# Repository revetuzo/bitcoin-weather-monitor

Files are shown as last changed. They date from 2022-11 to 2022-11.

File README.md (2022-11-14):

# bitcoin-weather-monitor

The Bitcoin weather monitor shows Bitcoin and weather data on a small TFT display and is powered by an ESP8266 NodeMCU board.

presentation

Bitcoin-weather-monitor

Shopping list:
- NodeMCU v3.4 ESP8266 board (31.2 mm x 58 mm)
- 1.77" TFT SPI display (128 x 160) with ST7735 driver (other sizes with the same resolution and driver may work too)
- GY-21 breakout board for the HTU21 or SHT21 temprature and humidity sensor
- cables with female/female Dupont connectors, approx. 10cm length
- some M2.5x8 and short M3 screws
- a 10 Ohm resistor and some heat-shrink tube (optional) (+ a soldering iron)

Instructions:
- print the enclosure on your 3D printer (four parts: enclosure, foot, backplate, sensor rack)
- solder the header pins to the PCBs if they do not come preassembled
- assemble the electronics as shown in the Fritzing drawing (10 Ohm resistor is optional, a simple wire is fine as well)
  - the drawing shows a BMP180 sensor, but the SHT21/HTU21 has the same pinout
- mount the electronics in the enclosure with the M2.5 and M3 screws (you need a long screwdriver and maybe a pair of tweezers)
- assemble the enclosure and the sensor rack
- get an Openweathermap free API key
- find your geographical location on OpenStreetMap
- run your own Bitcoin node (optional, but highly recommended anyway!)
- install Arduino IDE 1.8.x
- install ESP8266 core in Arduino IDE
- install libraries in Arduino IDE:
  - ArduinoHttpClient
  - ArduinoJson
  - Adafruit_GFX
  - Adafruit_ST7735
  - Sodaq_SHT2x
- find and follow instructions on how to connect your NodeMCU board with Arduino IDE via USB
- modify the .ino sketch file:
  - #define MY_TZ, this string defines your timezone and DST rules (set to GMT/London by default)
  - point char mempoolserver[] at your own node or just leave it at the default mempool.space address
  - char weatherAPIString: here you have to place your latitude, longitude, and Openweathermap API key
  - enter your WiFi SSID and password in arduino_secrets.h
  - (optional) you can change the date format in the tftClockScreen() function (default is European / German style)
  - (optional) you can change the temperature units in the tftTempWeatherScreen() function
  - (optional) change the data update intverval (5 min) and time per screen (5 s) with int dataUpdateInterval and int timePerScreen in the sketch header
- compile the sketch and upload to your NodeMCU board
- use the Serial Monitor during first startup to check that all data are correctly retrieved
  
Notes:
- The holes for the screws can be loose or tight, depending on how well your printer profile is tuned. To tune the hole sizes, you may play with the flow settings, or use the horizontal hole expansion in Cura 5.x. The hole diameters work fine on my Ender 3 V2 with direct drive mod and a 0.3mm nozzle.
- NTP is included in the latest ESP8266 core library and does not require additional libraries. Sync is automatically performed whenever we turn on WiFi.
- See https://github.com/nayarsystems/posix_tz_db/blob/master/zones.csv for timezone strings.
- We put the ESP8266 into sleep mode as much as possible. WiFi is only turned on during data update. Otherwise, the module is put into "light sleep" mode. This requires some code tweaking, but reduces the current draw by approximately 8 mA and reduces the heat load on the temperature sensor. See the function lightSleep() for the annoying details.
- The 10 Ohm resistor for the TFT LED is optional. It reduces the screen brightness a bit and reduces the current draw by approximately 15 mA (roughly 30%).
- The sensor has to be placed outside the enclosure, because the device has a constant power consumption of 160 mW, which heats the sensor too much for reliable measurements.
- If you have problems connecting the NodeMCU board, the cable might be an issue. Make sure you have a high-quality cable suitable for data transfer (not power-only!).
- Once we reach seven-digit block height, the font size will have to be adjusted. (Too lazy for automation).
- The TX fees are the "immediate" (red), "10 min" (orange), and "30 min" (green) TX fees estimated by mempool.
- The smaller NodeMCU v3.2 board will also work. But it will need a different backplate, will have to adapt the design later.
- You can remove parts of the code quite easily: E.g. you don't want the temperature and weather data, just remove the related function calls in setup() and loop(). Additionally, you can remove the associated calls and variable declarations in the header and delete the associated functions in the .ino sketch altogether.

To Do:
- The data types for the various variables are not optimized yet.
- Better error handling.
- Make an enclosure that fits a battery pack?
- Come up with a better idea for the temperature sensor placement?
- Use a separate configuration file for user-configurable parameters.
- ...

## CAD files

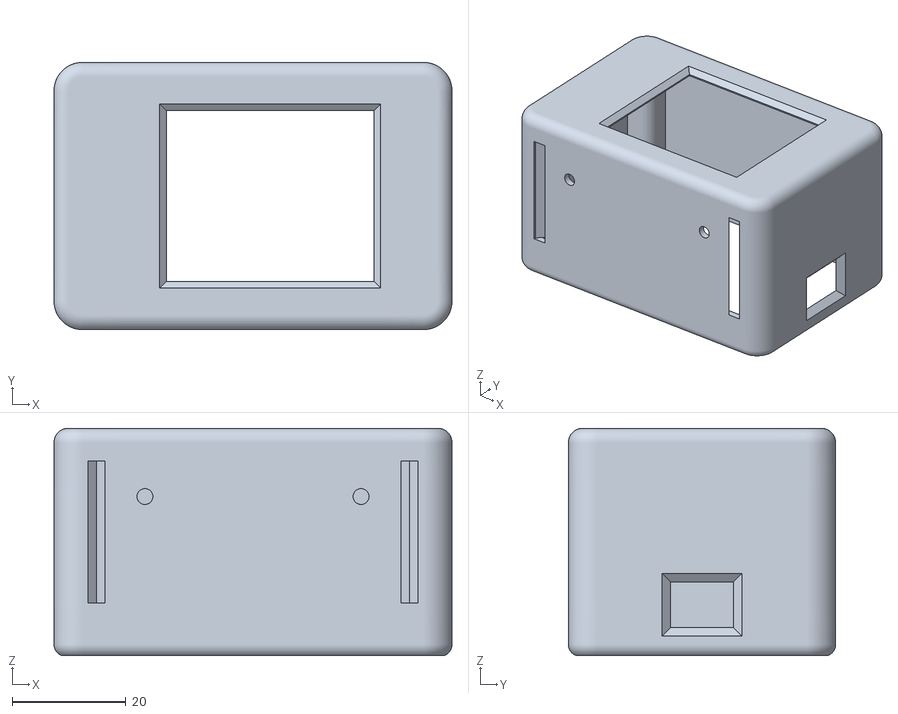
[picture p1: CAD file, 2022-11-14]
enclosure/body.stl
70.0 x 47.0 x 40.0

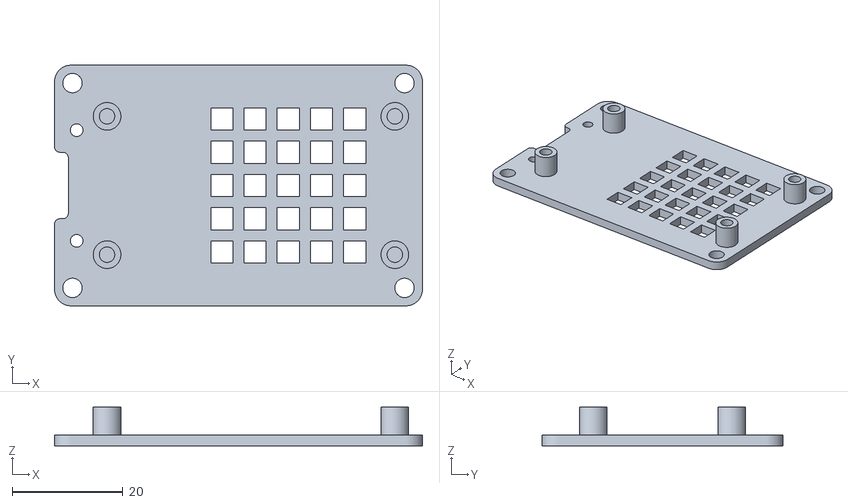
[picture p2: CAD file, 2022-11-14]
enclosure/backplate.stl
66.5 x 43.5 x 7.00

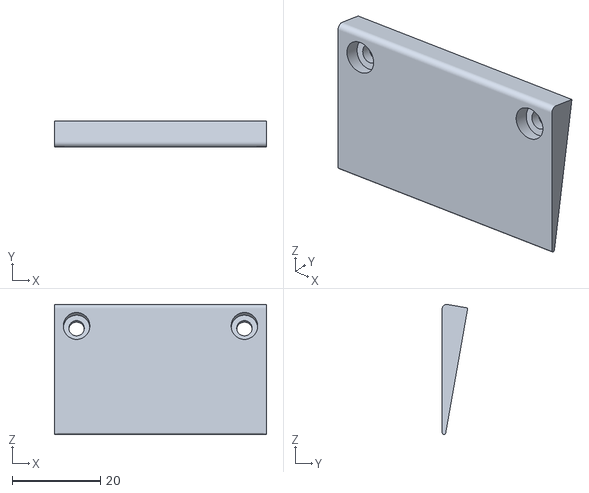
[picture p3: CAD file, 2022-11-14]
enclosure/foot.stl
48.0 x 5.79 x 29.5

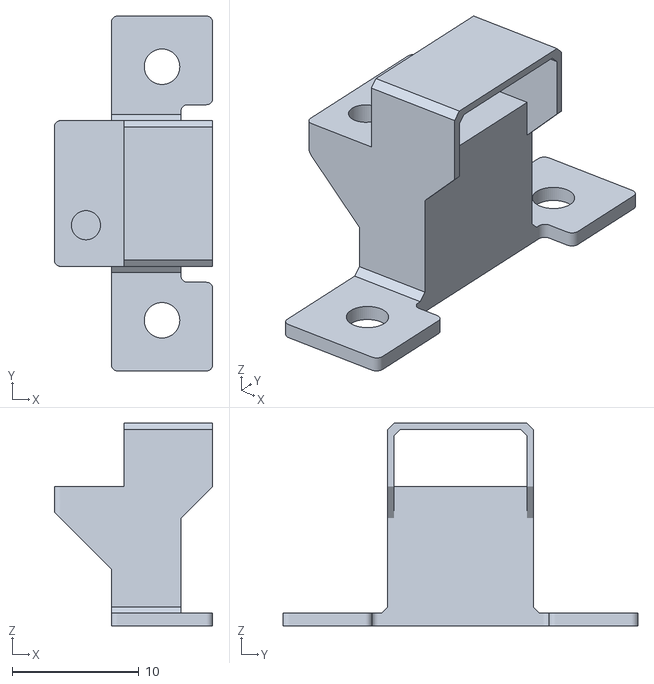
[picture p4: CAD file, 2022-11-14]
enclosure/sensor_rack.stl
12.5 x 28.0 x 16.0

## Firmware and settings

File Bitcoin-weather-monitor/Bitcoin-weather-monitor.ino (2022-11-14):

/*
 The Bitcoin weather monitor.
 A little client for displaying various Bitcoin related information using an ESP8266 dev board (NodeMCU).
 By @revetuzo.
 Sept 22, 2022

 Price API examples:
 https://www.bitstamp.net/api/v2/ticker/btcusd/, look for "last" in JSON response
 https://api.bitfinex.com/v1/pubticker/btcusd, look for "mid" in JSON response
 https://api.binance.com/api/v3/ticker/price?symbol=BTCUSDT, look for "price" in JSON response

 Bitstamp seems most reliable and stable.

 NTP configuration along the lines of https://werner.rothschopf.net/202011_arduino_esp8266_ntp_en.htm.
 Thanks to integration in ESP core and time library, almost nothing has to be done to integrate NTP!

 Note about the timed light-sleep mode: timers are stopped during light sleep, so we need to keep track of time
 manually through light sleep. This may lead to some time drift, which is not a big problem though,
 because NTP is polled automatically whenever we reconnect to WiFi on data update.
 See here for more details: https://github.com/esp8266/Arduino/tree/master/libraries/esp8266/examples/LowPowerDemo
 */

// Core, WiFi and connectivity related libraries
#include <ESP8266WiFi.h>

extern "C" {
#include "user_interface.h"
}

#include <ArduinoHttpClient.h>
#include <ArduinoJson.h>
#include <WiFiClientSecure.h>

// communication with the TFT via SPI
#include <SPI.h>

// time library for handling NTP and date/time, NTP callback
#include <time.h>
#include <coredecls.h>

// Configuration of NTP
#define MY_NTP_SERVER "pool.ntp.org"           
#define MY_TZ "GMT0BST,M3.5.0/1,M10.5.0" // London

// temperature and humidity sensor (SHT21 compatible) via I2C
#include <Wire.h>
#include <Sodaq_SHT2x.h>

// TFT libraries for 1.8" or 1.77" 160x128 display with ST7735 display controller
#include <Adafruit_GFX.h>    // Core graphics library
#include <Adafruit_ST7735.h> // Hardware-specific library for ST7735

// include fonts
#include <Fonts/FreeSansBold9pt7b.h>
#include <Fonts/FreeSansBold12pt7b.h>
#include <Fonts/FreeSansBold18pt7b.h>
#include <Fonts/FreeSansBold24pt7b.h>

// define pins for the TFT display, necessary for compatibility with default I2C pins for temperature sensor
#define TFT_CS         2 //NodeMCU pin D4
#define TFT_RST        16                                            
#define TFT_DC         0 //NodeMCU pin D3

// define colors
#define TWHITE ST7735_WHITE
#define TBLACK ST7735_BLACK
#define TORANGE ST7735_ORANGE
#define TGREEN ST7735_GREEN
#define TBLUE ST7735_BLUE
#define TCYAN ST7735_CYAN

// http://www.barth-dev.de/online/rgb565-color-picker/
#define DARKRED 0x5000 //(RGB 80 / 0 / 0)
#define DARKGREEN 0x0280 // (RGB 0 / 0 / 80)
#define DARKYELLOW 0x51E0 // (RGB 80 / 60 / 0)


// assign tft object
Adafruit_ST7735 tft = Adafruit_ST7735(TFT_CS, TFT_DC, TFT_RST);

// secure WiFi client
WiFiClientSecure sslclient;

// servers and clients
char priceserver[] = "www.bitstamp.net";
char mempoolserver[] = "mempool.space";
char weatherserver[] = "api.openweathermap.org";

HttpClient priceclient = HttpClient(sslclient, priceserver, 443);
HttpClient mempoolclient = HttpClient(sslclient, mempoolserver, 443);
HttpClient weatherclient = HttpClient(sslclient, weatherserver, 443);

// the openweathermap API string holds the geographic coordinates and the (free) API key
char weatherAPIString[] = "/data/2.5/weather?lat=51.5&lon=0.0&appid=MYAPIKEY";

// JSON documents for data processing
StaticJsonDocument<2048> doc;
StaticJsonDocument<2048> weather;

// WiFi secrets
#include "arduino_secrets.h" 
char ssid[] = SECRET_SSID;        // your network SSID (name)
char pass[] = SECRET_PASS;        // your network password (use for WPA, or use as key for WEP)
int status = WL_IDLE_STATUS;      // the WiFi radio's status

// timers and intervals
int lastDataUpdate = 0;
int dataUpdateInterval = 5*60;  // data update interval, 5 minutes;

int timePerScreen = 5000; // show each screen for milliseconds given by this number

// time related variables and parameters
time_t now;                         // this is the epoch
tm tm;                              // the structure tm holds time information in a more convient way

// callback function for NTP sync
void timeIsSet(bool from_sntp) {  
  if (from_sntp){
    Serial.println();
    Serial.println("[NTP] NTP sync complete.");
    Serial.println();
  }
}

//Week Days
String weekDaysFull[7]={"Sunday", "Monday", "Tuesday", "Wednesday", "Thursday", "Friday", "Saturday"};
//String weekDays[7]={"Sun", "Mon", "Tue", "Wed", "Thu", "Fri", "Sat"};

//Month names
String months[12]={"January", "February", "March", "April", "May", "June", "July", "August", "September", "October", "November", "December"};


String price = "NaN";
long sats;

String blockheight = "0";
int feerates[3] = {0, 0, 0};

float temperature;
float humidity;

float temperatureSelfHeatingCorrection = -0.4; // compensate for the heating of the sensor by the NodeMCU board and the display


// END INCLUDES AND DECLARATIONS

////////////////////////////////////////////////////////////////////////////////////////////////////////
////////////////////////////////////////////////////////////////////////////////////////////////////////
////////////////////////////////////////////////////////////////////////////////////////////////////////

// BEGIN SETUP

void setup() {
  // Start NTP
  configTime(MY_TZ, MY_NTP_SERVER);
  settimeofday_cb(timeIsSet);

  //Initialize serial (for diagnostic output)
  Serial.begin(115200);

  // enable Wire for I2C communication
  Wire.begin();

  // initialize TFT
  tft.initR(INITR_BLACKTAB);      // Init ST7735S chip, black tab
  tft.fillScreen(TBLACK);
  tft.setRotation(-1);

  tft.println("Bitcoin Weather Monitor");
  
  tft.println("Connecting to WiFi:");
  tft.print(ssid);

  Serial.print("Attempting to connect to SSID: ");
  Serial.print(ssid);

  WiFi.mode(WIFI_STA);
  
  WiFi.begin(ssid, pass);
  while (WiFi.status() != WL_CONNECTED)
  {
    delay(500);
    Serial.print(".");
    tft.print(".");
  }
  // you're connected now, so print out the data:
  Serial.println(" connected!");
  printWifiData();

  tft.println(" connected!");
  tft.print("IP: ");
  tft.println(WiFi.localIP());

  delay(100);

  // we choose to omit the certificate check for simplicity
  sslclient.setInsecure();
  
  tft.print("Price data... ");
  getPrice();
  lastDataUpdate = millis();
  if (price != "NaN"){
      tft.println("OK!");
  }
  delay(100);

  tft.print("Mempool data... "); 
  getBlockHeight();
  getRecommendedFees();
  lastDataUpdate = millis();
  if (blockheight != "0"){
    tft.println("OK!");
  }
  delay(100);

  tft.print("Local weather data... "); 
  getWeather();
  tft.println("OK!"); 
  
  delay(100);

  tft.print("Temperature and humidity sensor... "); 
  humidity = SHT2x.GetHumidity();
  temperature = SHT2x.GetTemperature();
  tft.println("OK!");  
  
  Serial.println();
  Serial.println("WiFi off");
  tft.println("WiFi off");
  WiFi.mode(WIFI_OFF);
  WiFi.forceSleepBegin(0xFFFFFFF);
  delay(10);

  time(&now);
  lastDataUpdate = now;
  
  delay(1000);

}

// END SETUP

////////////////////////////////////////////////////////////////////////////////////////////////////////
////////////////////////////////////////////////////////////////////////////////////////////////////////
////////////////////////////////////////////////////////////////////////////////////////////////////////

// BEGIN LOOP

void loop() {  
  // show clock screen
  tftClockScreen();

  // update data if last update is too long ago, given by dataUpdateInterval
  // while updating, keep showing the clock screen
  time(&now);
  if (now - lastDataUpdate >= dataUpdateInterval){
    dataUpdate();
    lastDataUpdate = now;
  }
  else {
    lightSleep(timePerScreen);
  }
  
  // update temperature and humidity, then show on screen
  getTempHum();
  tftTempWeatherScreen();
  lightSleep(timePerScreen);

  // show price screen
  tftPriceScreen();
  lightSleep(timePerScreen);

  // show mempool data screen
  tftMempoolScreen();
  lightSleep(timePerScreen);
}


// END LOOP

////////////////////////////////////////////////////////////////////////////////////////////////////////
////////////////////////////////////////////////////////////////////////////////////////////////////////
////////////////////////////////////////////////////////////////////////////////////////////////////////




// Temperature and Weather related functions and screens

void getTempHum() {
  // use an exponential moving average with alpha = 0.5 to get more stable readings
  float alpha = 0.5;
  humidity = alpha * SHT2x.GetHumidity() + (1-alpha) * humidity;
  temperature = alpha * SHT2x.GetTemperature() + (1-alpha) * temperature;
}


void tftTempWeatherScreen()
{
  Serial.println("[TEMPERATURE AND WEATHER SCREEN]");
  tft.fillScreen(TBLACK);

  // Let's draw a small table for debugging
  //tft.drawRect(0, 0, tft.width(), tft.height(), TWHITE);
  //tft.drawLine(0, 63, tft.width(), 63, TWHITE);

  char buffer[16];
  sprintf(buffer, "%4.1fC  %4.1f%% ", (temperature + temperatureSelfHeatingCorrection), humidity);

  tft.setFont(&FreeSansBold9pt7b);
  tft.setCursor(5,18);
  tft.setTextColor(TGREEN);
  tft.println("Indoor");
  
  tft.setFont(&FreeSansBold12pt7b);
  tft.setTextColor(TWHITE);
  drawCenterString(buffer, 79, 63-4-15);


  tft.setFont(&FreeSansBold9pt7b);
  tft.setCursor(5,63+18-15);
  tft.setTextColor(TGREEN);
  tft.println("Outdoor");

  const char* outdoorDescription = weather["weather"][0]["description"];
  const float outdoorTemperature = weather["main"]["temp"];
  const int outdoorHumidity = weather["main"]["humidity"];
  const int outdoorPressure = weather["main"]["pressure"];
  const float outdoorWindspeed = weather["wind"]["speed"];

  tft.setFont(&FreeSansBold9pt7b);
  tft.setTextColor(TWHITE);
  
  sprintf(buffer, "%.1fC    %i%%", outdoorTemperature-273.15, outdoorHumidity);  
  drawCenterString(buffer, 79, 127-4-36);

  sprintf(buffer, "%ihPa  %i km/h", outdoorPressure, (int)(outdoorWindspeed*3.6));  
  drawCenterString(buffer, 79, 127-4-18);

  tft.setTextColor(TCYAN);
  drawCenterString(outdoorDescription, 79, 127-4);
}

void getWeather() {
  Serial.println();
  Serial.print("Making GET request to openweathermap server for current weather: ");
  Serial.println(weatherserver);
  
  weatherclient.get(weatherAPIString);

  // read the status code and body of the response
  int statusCode = weatherclient.responseStatusCode();
  String response = weatherclient.responseBody();

  Serial.print("Status code: ");
  Serial.println(statusCode);
  Serial.print("Response: ");
  Serial.println(response);

  auto error = deserializeJson(weather, response);
  if (error) {
    Serial.print(F("deserializeJson() failed with code "));
    Serial.println(error.c_str());
    return;
  }

  const char* outdoorDescription = weather["weather"][0]["description"];
  const float temperature = weather["main"]["temp"];
  
}
////////////////////////////////////////////////////////////////////////////////////////////////////////

// Price related functions and screens

void getPrice() {
  Serial.println();
  Serial.print("Making GET request to price server: ");
  Serial.println(priceserver);
  
  //priceclient.get("/v1/pubticker/btcusd");  // bitfinex
  priceclient.get("/api/v2/ticker/btcusd/"); // bitstamp
  //priceclient.get("/api/v3/ticker/price?symbol=BTCUSDT");  // binance
  

  // read the status code and body of the response
  int statusCode = priceclient.responseStatusCode();
  String response = priceclient.responseBody();

  Serial.print("Status code: ");
  Serial.println(statusCode);
  Serial.print("Response: ");
  Serial.println(response);

  auto error = deserializeJson(doc, response);
  if (error) {
    Serial.print(F("deserializeJson() failed with code "));
    Serial.println(error.c_str());
    return;
  }
  
  //const char* p = doc["mid"];  // bitfinex
  const char* p = doc["last"];  // bitstamp
  //const char* p = doc["price"];  // binance
  price = String(p);

  sats = 1/price.toFloat() * 100000000;

  Serial.print("Price: ");
  Serial.println(price.toFloat());
  Serial.print("Sats per USD: ");
  Serial.println(sats);
  
}


void tftPriceScreen()
{
  Serial.println("[PRICE SCREEN]");

  tft.fillScreen(TBLACK);

  // Let's draw a small table for debugging
  //tft.drawRect(0, 0, tft.width(), tft.height(), TWHITE);
  //tft.drawLine(0, 63, tft.width(), 63, TWHITE);
  
  tft.setFont(&FreeSansBold9pt7b);
  tft.setCursor(5,18);
  tft.setTextColor(TORANGE);
  tft.println("BTCUSD");
  
  tft.setFont(&FreeSansBold24pt7b);
  tft.setTextColor(TWHITE);
  drawAlignRightString(price.c_str(), 159-3, 63-4);

  tft.setFont(&FreeSansBold9pt7b);
  tft.setCursor(5,63+18);
  tft.setTextColor(TORANGE);
  tft.println("Sats per USD");
  
  tft.setFont(&FreeSansBold24pt7b);
  tft.setTextColor(TWHITE);
  drawAlignRightString(String(sats).c_str(), 159-3, 127-4);
}

////////////////////////////////////////////////////////////////////////////////////////////////////////

// Mempool related functions and screens

void tftMempoolScreen()
{
  Serial.println("[MEMPOOL SCREEN]");

  tft.fillScreen(TBLACK);

  // Let's draw a small table for debugging
  //tft.drawRect(0, 0, tft.width(), tft.height(), TWHITE);
  //tft.drawLine(0, 63, tft.width(), 63, TWHITE);
  
  tft.setFont(&FreeSansBold9pt7b);
  tft.setCursor(3,18);
  tft.setTextColor(TORANGE);
  tft.println("Block Height");
  
  tft.setFont(&FreeSansBold24pt7b);
  tft.setTextColor(TWHITE);
  drawAlignRightString(blockheight.c_str(), 159-3, 63-4);

  tft.setFont(&FreeSansBold9pt7b);
  tft.setCursor(3,63+22);
  tft.setTextColor(TORANGE);
  tft.println("TX Fees (sats/vB)");
  
  tft.setFont(&FreeSansBold12pt7b);
  tft.setTextColor(TWHITE);
  char buffer[16];
  tft.fillRect(0, 127-4-10-20, 54, 25, DARKRED);
  tft.fillRect(54, 127-4-10-20, 54, 25, DARKYELLOW);
  tft.fillRect(107, 127-4-10-20, 53, 25, DARKGREEN);
  
  sprintf(buffer, "%4d", feerates[0]);
  drawAlignRightString(buffer, 53-8, 127-4-10);
  
  sprintf(buffer, "%6d", feerates[1]);
  drawAlignRightString(buffer, 107-8, 127-4-10);
  
  sprintf(buffer, "%6d", feerates[2]);  
  drawAlignRightString(buffer, 159-8, 127-4-10);

}

void getBlockHeight() {
  Serial.println();
  Serial.print("Making GET request to mempool server for block height: ");
  Serial.println(mempoolserver);
  
  mempoolclient.get("/api/blocks/tip/height");

  // read the status code and body of the response
  int statusCode = mempoolclient.responseStatusCode();
  String response = mempoolclient.responseBody();

  Serial.print("Status code: ");
  Serial.println(statusCode);
  Serial.print("Response: ");
  Serial.println(response);

  auto error = deserializeJson(doc, response);
  if (error) {
    Serial.print(F("deserializeJson() failed with code "));
    Serial.println(error.c_str());
    return;
  }

  blockheight = String(response);
}

void getRecommendedFees() {
  Serial.println();
  Serial.print("Making GET request to mempool server for recommended fees: ");
  Serial.println(mempoolserver);
  
  mempoolclient.get("/api/v1/fees/recommended");

  // read the status code and body of the response
  int statusCode = mempoolclient.responseStatusCode();
  String response = mempoolclient.responseBody();

  Serial.print("Status code: ");
  Serial.println(statusCode);
  Serial.print("Response: ");
  Serial.println(response);

  auto error = deserializeJson(doc, response);
  if (error) {
    Serial.print(F("deserializeJson() failed with code "));
    Serial.println(error.c_str());
    return;
  }
  
  const int f = doc["fastestFee"];
  const int m = doc["halfHourFee"];
  const int s = doc["hourFee"];
  feerates[0] = f;
  feerates[1] = m;
  feerates[2] = s;

  Serial.println("Fees: " + String(f) + " " + String(m) + " " + String(s));
}

////////////////////////////////////////////////////////////////////////////////////////////////////////

// clock related functions and screens

void tftClockScreen()
{
  Serial.println("[CLOCK SCREEN]");

  time(&now);
  localtime_r(&now, &tm);

  Serial.println(now);
  
  tft.fillScreen(TBLACK);

  char currentTimeFormatted[5];
  sprintf(currentTimeFormatted, "%02i:%02i", tm.tm_hour, tm.tm_min); 
  
  // Let's draw a small table for debugging
  //tft.drawRect(0, 0, tft.width(), tft.height(), TWHITE);
  //tft.drawLine(0, 63, tft.width(), 63, TWHITE);  
  
  tft.setFont(&FreeSansBold24pt7b);
  tft.setTextColor(TWHITE);
  drawCenterString(currentTimeFormatted, 79, 63-10);

  tft.setFont(&FreeSansBold12pt7b);
  tft.setTextColor(TWHITE);
  drawCenterString(weekDaysFull[tm.tm_wday].c_str(), 79, 127-4-35);

  char currentDateFormatted[10];
  sprintf(currentDateFormatted, "%02d.%02d.%04d", tm.tm_mday, tm.tm_mon+1, tm.tm_year+1900);  
  
  drawCenterString(currentDateFormatted, 79, 127-4-10);
}


////////////////////////////////////////////////////////////////////////////////////////////////////////

// WiFi and connectivity related functions

void dataUpdate(){
    Serial.println();
    Serial.println("[DATA UPDATE]: Retrieving data...");
    tft.setFont();
    drawCenterString("Updating data...", 79, 5);
    Serial.print("[DATA UPDATE]: WiFi on and reconnect");
    WiFi.forceSleepWake();
    delay(10);
    WiFi.mode(WIFI_STA);
    WiFi.begin(ssid, pass);
    while (WiFi.status() != WL_CONNECTED) {
      delay(500);
      Serial.print(".");
    }
    Serial.println("OK!");
    
    getPrice();
    getBlockHeight();
    getRecommendedFees();
    getWeather();
    lastDataUpdate = millis();  
      
    Serial.println("[DATA UPDATE]: WiFi off");
    WiFi.mode(WIFI_OFF);
    WiFi.forceSleepBegin(0xFFFFFFF);
    delay(10);
}

    
void printWifiData() {
  // print your board's IP address:
  IPAddress ip = WiFi.localIP();
  Serial.print("IP Address: ");
  Serial.println(ip);

  // print your MAC address:
  byte mac[6];
  WiFi.macAddress(mac);
  Serial.print("MAC address: ");
  printMacAddress(mac);

  // print the SSID of the network you're attached to:
  Serial.print("SSID: ");
  Serial.println(WiFi.SSID());

  // print the received signal strength:
  long rssi = WiFi.RSSI();
  Serial.print("signal strength (RSSI):");
  Serial.println(rssi);

}

void printMacAddress(byte mac[]) {
  for (int i = 5; i >= 0; i--) {
    if (mac[i] < 16) {
      Serial.print("0");
    }
    Serial.print(mac[i], HEX);
    if (i > 0) {
      Serial.print(":");
    }
  }
  Serial.println();
}



////////////////////////////////////////////////////////////////////////////////////////////////////////

// helpers for displaying text on the TFT

// x is the x-coordinate of the string center
// y is the y-coordinate of the bottom of the string
void drawCenterString(const char *buf, int x, int y)
{
    int16_t x1, y1;
    uint16_t w, h;
    tft.setTextWrap(false);
    tft.getTextBounds(buf, x, y, &x1, &y1, &w, &h); //calc width of new string
    tft.setCursor(x - w / 2, y);
    tft.print(buf);
}

// x is the x-coordinate of the string bottom right corner
// y is the y-coordinate of the string bottom right corner
void drawAlignRightString(const char *buf, int x, int y)
{
    int16_t x1, y1;
    uint16_t w, h;
    tft.setTextWrap(false);
    tft.getTextBounds(buf, x, y, &x1, &y1, &w, &h); //calc width of new string
    tft.setCursor(x - w, y);
    tft.print(buf);
}

////////////////////////////////////////////////////////////////////////////////////////////////////////

// internal helpers

// performs light sleep for a given time (in ms)
void lightSleep(uint32_t sleepTime){
  Serial.print("Light sleep (");
  Serial.print(sleepTime);
  Serial.print(" ms) ...");
  Serial.flush();

  // we need to keep track of time through light sleep manually, because timers are turned off during sleep
  // get current epoch
  time(&now);
  uint32_t sleepStart = now;

  wifi_set_opmode(NULL_MODE);
  wifi_fpm_set_sleep_type(LIGHT_SLEEP_T);
  wifi_fpm_open();
  wifi_fpm_set_wakeup_cb(wakeupCallback);  // set wakeup callback
  wifi_fpm_do_sleep(sleepTime * 1000);        // Sleep range = 10000 ~ 268,435,454 uS (0xFFFFFFE, 2^28-1)
  delay(sleepTime + 1);                // delay needs to be 1 ms longer than sleep or it only goes into Modem Sleep
  Serial.println("... continue.");  // the interrupt callback hits before this is executed

  // update system time with time before sleep plus duration of sleep
  struct timeval tv;
  tv.tv_sec = time_t(sleepStart + sleepTime/1000);
  tv.tv_usec = suseconds_t(0);  // this must be set, it's full of garbage otherwise!
  settimeofday(&tv, NULL);
  WiFi.mode(WIFI_OFF);             // after waking up from light sleep we have to force the modem off, otherwise
  WiFi.forceSleepBegin(0xFFFFFFF); // it is turned back on and does not even go to auto modem-sleep
}

// callback function on wake-up to demonstrate that light sleep operates correctly
void wakeupCallback() { 
  Serial.println(" Callback OK! ");
  Serial.flush();
  wifi_fpm_close();
}

// set initial delay for NTP sync after connection
uint32_t sntp_startup_delay_MS_rfc_not_less_than_60000 ()
{
  return 2000UL; // 2s
}



// END SKETCH
////////////////////////////////////////////////////////////////////////////////////////////////////////
////////////////////////////////////////////////////////////////////////////////////////////////////////
////////////////////////////////////////////////////////////////////////////////////////////////////////
